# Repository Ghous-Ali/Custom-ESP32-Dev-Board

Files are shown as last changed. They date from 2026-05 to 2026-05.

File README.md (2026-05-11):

# Custom ESP32 Development Board

A from-scratch ESP32-WROOM-32E development board designed in KiCad 9.0.7 on a 4-layer PCB stackup.

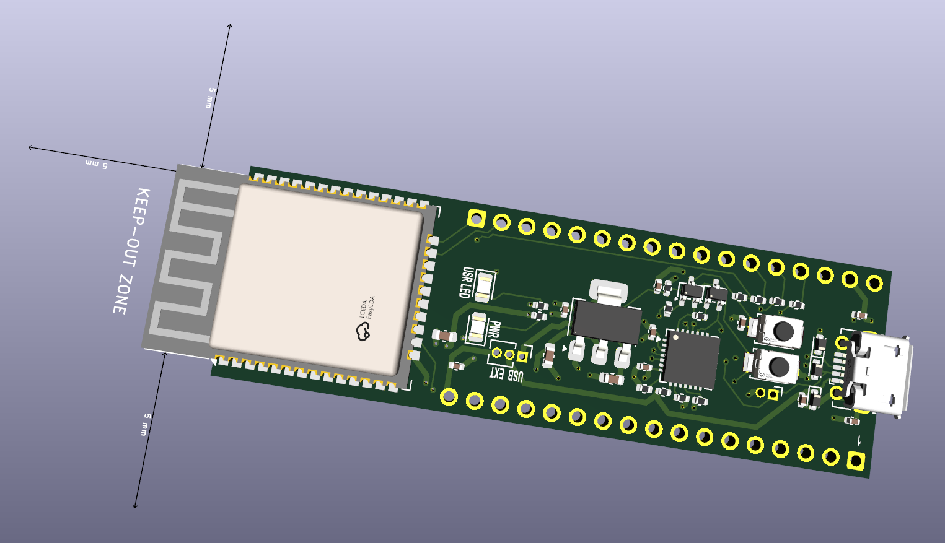
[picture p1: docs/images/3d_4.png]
Front Perspective

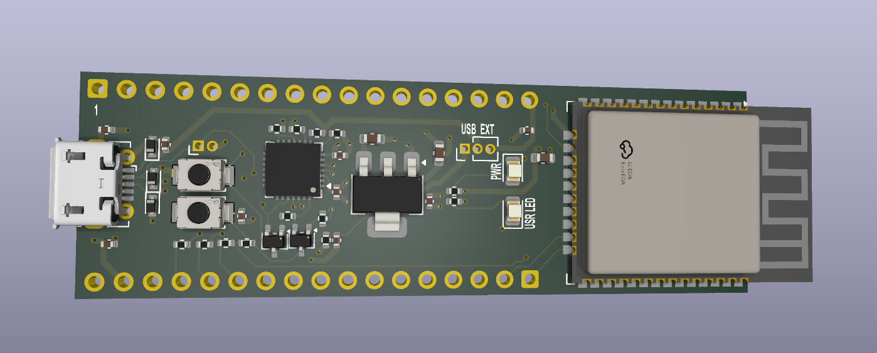
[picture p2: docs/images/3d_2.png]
Top View

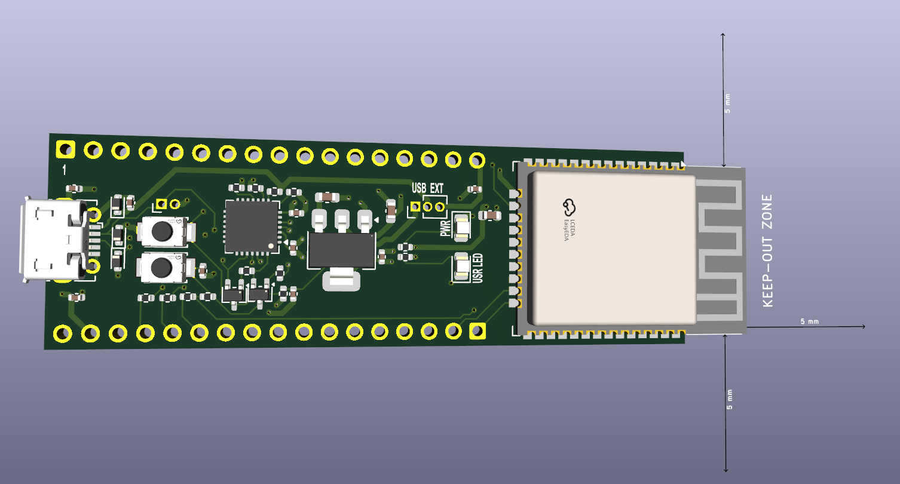
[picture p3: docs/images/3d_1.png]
Front Close-Up

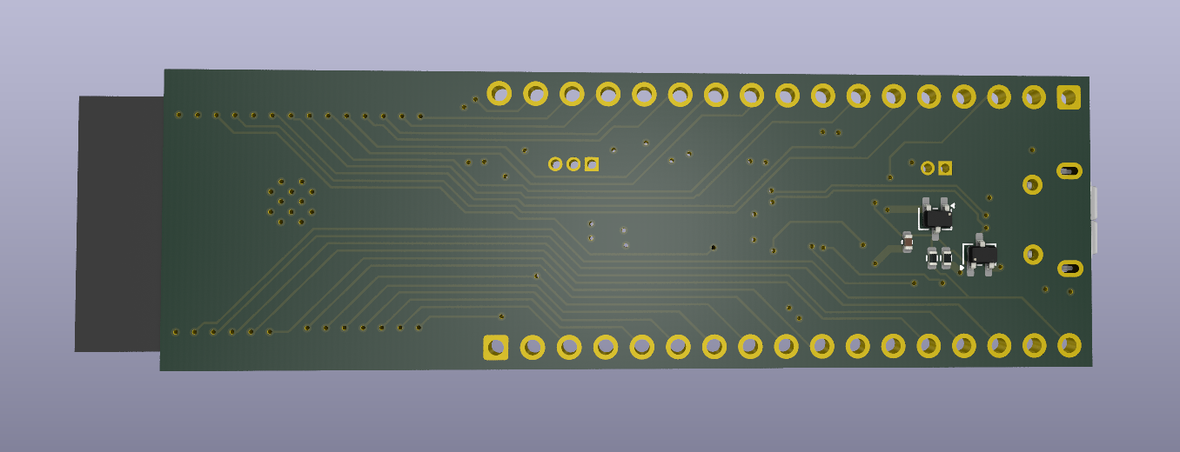
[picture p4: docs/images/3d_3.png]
Back View

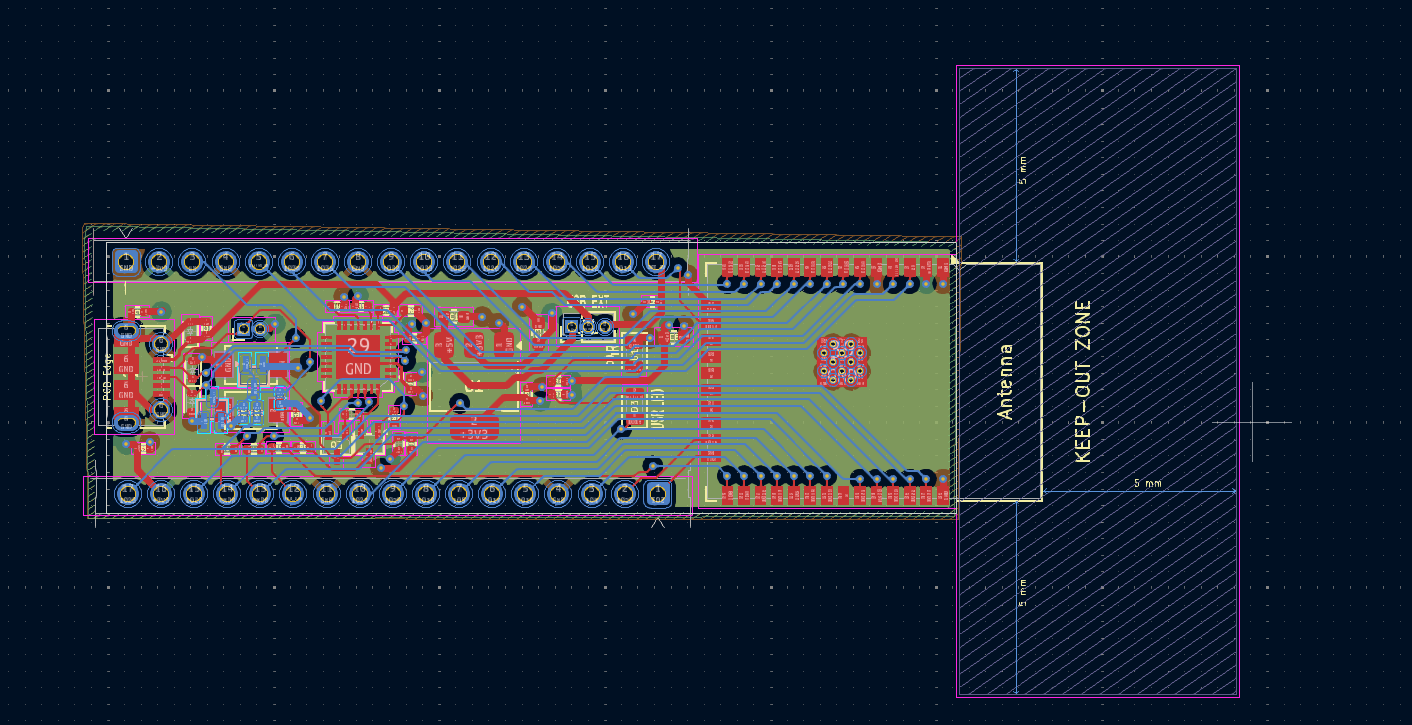
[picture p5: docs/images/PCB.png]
PCB Layout

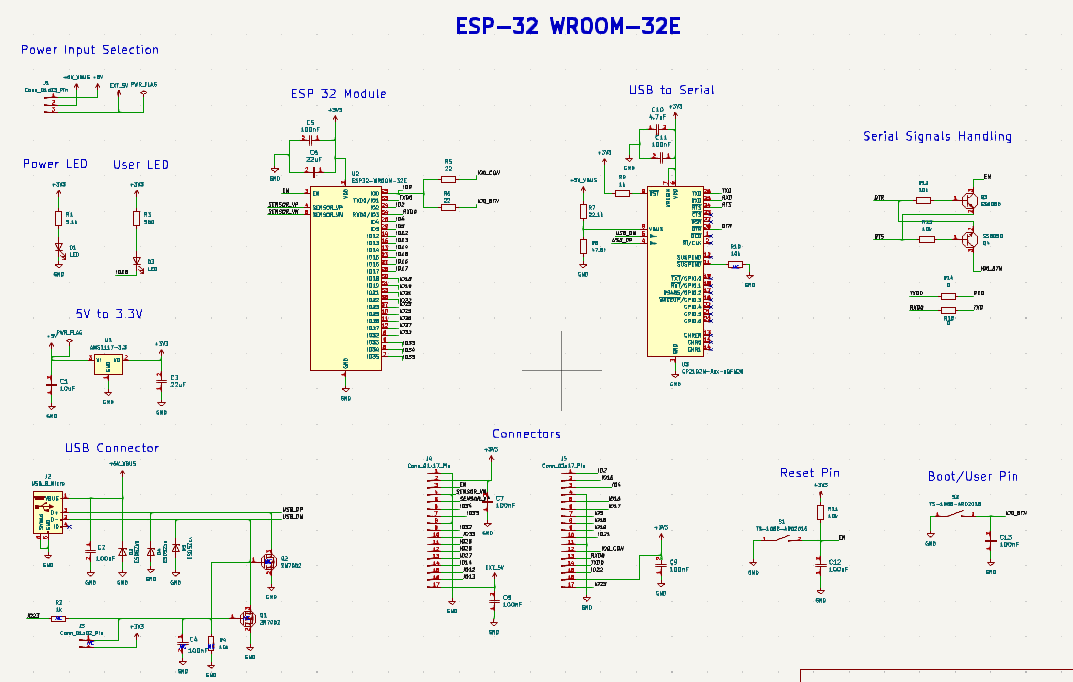
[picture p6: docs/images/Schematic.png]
Schematic


## Features

- **MCU:** ESP32-WROOM-32E (WiFi + Bluetooth, dual-core Xtensa LX6)
- **USB-to-Serial:** CP2102N-A02-GQFN28 with full auto-programming support (DTR/RTS via 2N7002 MOSFETs)
- **Power:** AMS1117-3.3V LDO with 22µF + 100nF input/output filtering; external 5V input option with power path selection
- **ESD Protection:** ESD5Zxx TVS diodes on USB D+/D- lines
- **User Interface:** Boot button, Reset button, Power LED, User LED
- **I/O:** Dual 17-pin headers — breadboard-compatible, exposing all usable GPIOs
- **RF:** Antenna keep-out zone with 5mm clearance on all sides — no copper pour under antenna area
- **PCB:** 4-layer stackup (Signal – GND – Power – Signal), designed for clean return paths and RF performance

## Schematic Overview

| Block | Key Components | Notes |
|---|---|---|
| ESP32 Module | ESP32-WROOM-32E | 38 pins exposed via castellated pads |
| USB-to-Serial | CP2102N, 2N7002 × 2 | Auto-reset circuit for one-click flashing |
| Power Regulation | AMS1117-3.3, SS8050 | 5V USB or external → 3.3V rail |
| ESD Protection | ESD5Zxx × 2 | On USB data lines |
| Decoupling | 100nF × 8, 22µF × 2, 10µF, 4.7µF | Distributed across power pins |

## 4-Layer Stackup Rationale

| Layer | Function |
|---|---|
| F.Cu | Signal routing + component pads |
| In1.Cu | Continuous ground plane |
| In2.Cu | Power distribution (3.3V, 5V) |
| B.Cu | Signal routing + component pads |

A dedicated ground plane on layer 2 ensures low-impedance return paths for high-speed USB signals and minimises EMI. Separating power onto its own inner layer reduces noise coupling to signal traces.

## Design Decisions

- **Auto-reset circuit:** Uses two 2N7002 N-channel MOSFETs driven by DTR and RTS from the CP2102N. This allows tools like `esptool.py` to automatically put the ESP32 into bootloader mode — no manual button pressing needed during upload.
- **Antenna keep-out:** 5mm clearance enforced on all sides of the ESP32 antenna area. No copper, traces, or components in this zone to preserve WiFi/Bluetooth performance.
- **External 5V input:** A 3-pin header (J1) allows powering the board from an external 5V source (e.g., battery pack or bench supply) independently of USB, with SS8050-based switching.
- **Pull-up/pull-down network:** Strapping pins (IO0, IO2, IO5, IO15) are configured via resistor network for default boot-from-flash behaviour.

## Repository Structure

```
Custom_ESP_Dev_Board/
├── hardware/                      # KiCad project files (.kicad_pro, .kicad_sch, .kicad_pcb)
├── production/
│   ├── gerbers/                   # Fabrication files
│   ├── BOM.csv                    # Bill of Materials
│   └── pick-and-place.csv        # Assembly positions
├── docs/
│   ├── images/                    # 3D renders, PCB layout, schematic screenshots
│   └── schematic.pdf             # Exported schematic PDF
├── LICENSE
└── README.md
```

## Tools Used

- **EDA:** KiCad 9.0.7
- **PCB Layers:** 4
- **Design Rules:** JLCPCB 4-layer capabilities (adjust as needed for your fab)

## Getting Started

1. Clone this repo
2. Open the `.kicad_pro` file in KiCad 9.0.7+
3. Generate Gerbers from PCB editor → File → Fabrication Outputs
4. Upload to your preferred PCB fab (JLCPCB, PCBWay, etc.)

## References

- [ESP32-WROOM-32E Datasheet](https://www.espressif.com/sites/default/files/documentation/esp32-wroom-32e_esp32-wroom-32ue_datasheet_en.pdf)
- [ESP32-DevKitC V4 Reference Schematic](https://dl.espressif.com/dl/schematics/esp32_devkitc_v4-sch.pdf)
- [CP2102N Datasheet](https://www.silabs.com/documents/public/data-sheets/cp2102n-datasheet.pdf)

## Licence

This project is open-source hardware. See [LICENSE](LICENSE) for details.

---

Designed by **Ghous Ali** — Electronics & Embedded Systems Engineer  
[LinkedIn](https://www.linkedin.com/in/ghousali13/) · [Email](Ghousali1019@email.com)

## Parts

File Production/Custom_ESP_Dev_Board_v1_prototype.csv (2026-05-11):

Comment | Footprint | Quantity | Designation | LCSC
D5,D4,D2 | D_SOD-523 | 3 | ESD5Zxx | C890620
R13,R11,R12,R10 | R_0402_1005Metric | 4 | 10k | C60490
C8,C11,C5,C7,C2,C12,C9,C13 | C_0402_1005Metric | 8 | 100nF | C60474
U2 | ESP32-WROOM-32D | 1 | ESP32-WROOM-32E | C701342
R7 | R_0402_1005Metric | 1 | 22.1k | C163478
S1,S2 | SW_TS-1088-AR02016 | 2 | TS-1088-AR02016 | C720477
C1 | C_0603_1608Metric | 1 | 10uF | C96446
C6,C3 | C_0603_1608Metric | 2 | 22uF | C59461
J2 | USB_Micro-B_Molex-105017-0001 | 1 | USB_B_Micro | C136000
D3,D1 | LED_0805_2012Metric | 2 | LED | C965815
R14,R15 | R_0402_1005Metric | 2 | 0 | C106231
R3 | R_0402_1005Metric | 1 | 560 | C163460
U3 | QFN-28-1EP_5x5mm_P0.5mm_EP3.35x3.35mm | 1 | CP2102N-Axx-xQFN28 | C964632
U1 | SOT-223-3_TabPin2 | 1 | AMS1117-3.3 | C347222
R9 | R_0402_1005Metric | 1 | 1k | C2906864
R5,R6 | R_0402_1005Metric | 2 | 22 | C114765
Q3,Q4 | SOT-323_SC-70 | 2 | SS8050 | C5189252
R8 | R_0402_1005Metric | 1 | 47.5k | C25896
C10 | C_0402_1005Metric | 1 | 4.7uF | C23733
R1 | R_0402_1005Metric | 1 | 5.1k | C105872

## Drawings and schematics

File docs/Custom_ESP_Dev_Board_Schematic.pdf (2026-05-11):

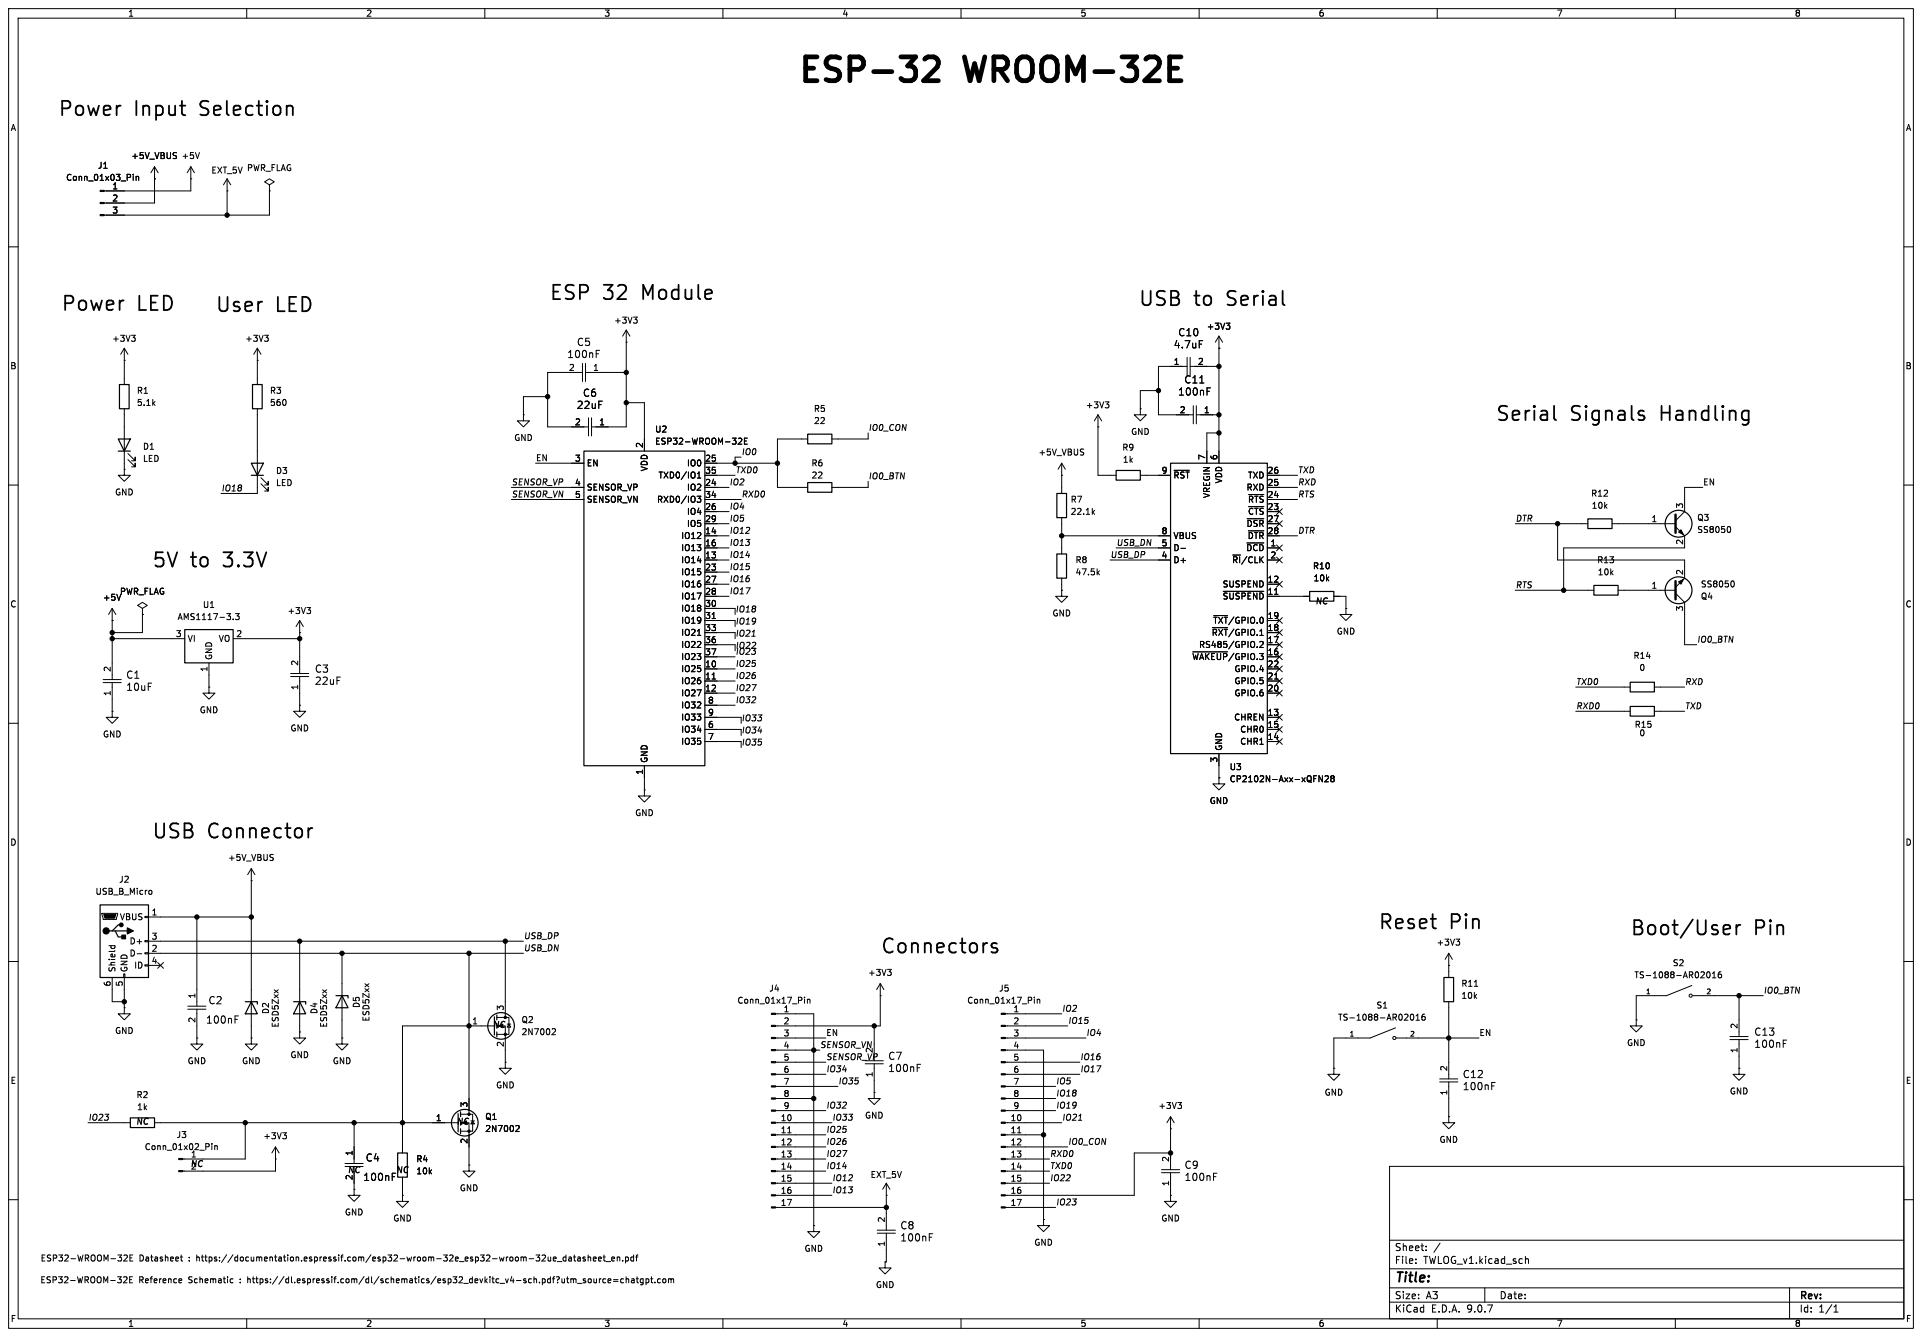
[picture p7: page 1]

3 TXD 26 RXD 25 ~{RTS} 24 ~{CTS} 23 ~{DSR} 27 ~{DTR} 28 ~{DCD}1 ~{RI}/CLK2 SUSPEND 12 ~{SUSPEND}11 ~{TXT}/GPIO.019 ~{RXT}/GPIO.118 RS485/GPIO.2 17 ~{WAKEUP}/GPIO.316 GPIO.4 22 GPIO.5 21 GPIO.6 20 CHREN 13 CHR0 15 CHR1 14 U3 CP2102N-Axx-xQFN28 GND GND

3 TXD 26 RXD 25 ~{RTS} 24 ~{CTS} 23 ~{DSR} 27 ~{DTR} 28 ~{DCD}1 ~{RI}/CLK2 SUSPEND 12 ~{SUSPEND}11 ~{TXT}/GPIO.019 ~{RXT}/GPIO.118 RS485/GPIO.2 17 ~{WAKEUP}/GPIO.316 GPIO.4 22 GPIO.5 21 GPIO.6 20 CHREN 13 CHR0 15 CHR1 14 C4

Id: 1/1 Title: File: TWLOG_v1.kicad_sch Sheet: /

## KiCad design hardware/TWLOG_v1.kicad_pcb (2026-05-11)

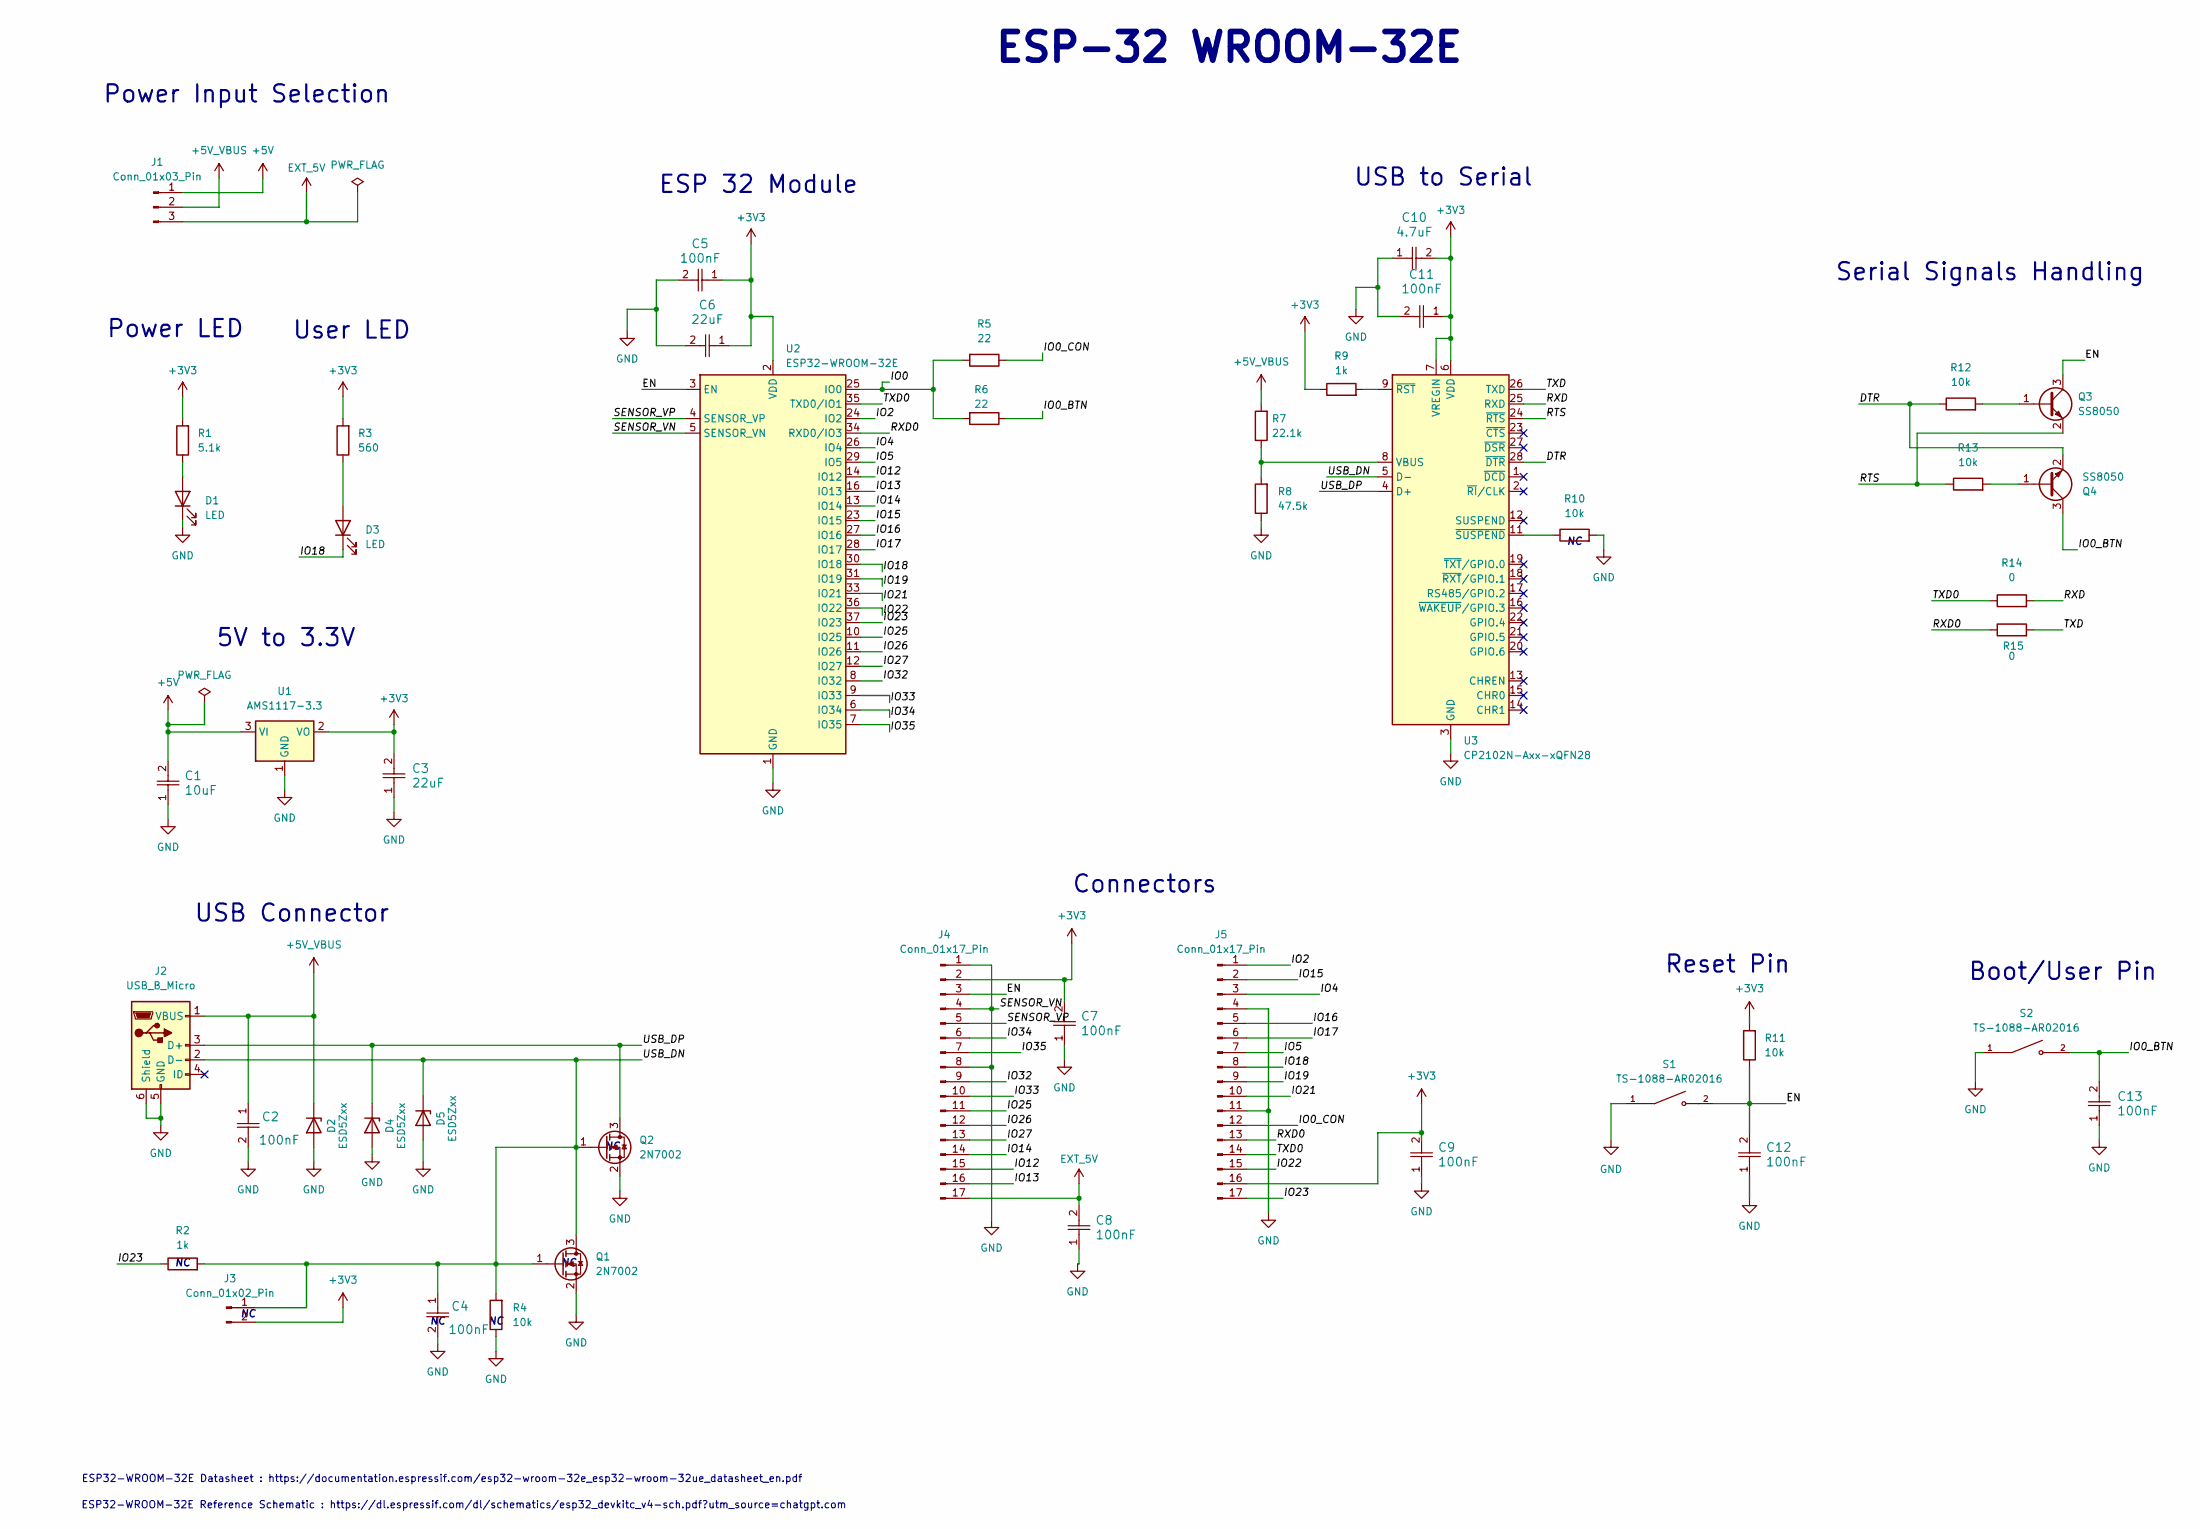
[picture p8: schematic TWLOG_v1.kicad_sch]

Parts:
C1: 10uF; C_0603_1608Metric
C2, C4, C5, C7, C8, C9, C11, C12, C13: 100nF; C_0402_1005Metric
C3, C6: 22uF; C_0603_1608Metric
C10: 4.7uF; C_0402_1005Metric
D1, D3: LED; LED_0805_2012Metric
D2, D4, D5: ESD5Zxx; D_SOD-523
J1: Conn_01x03_Pin; PinHeader_1x03_P1.27mm_Vertical
J2: USB_B_Micro; USB_Micro-B_Molex-105017-0001
J3: Conn_01x02_Pin; PinHeader_1x02_P1.27mm_Horizontal
J4, J5: Conn_01x17_Pin; Molex_SL_171971-0017_1x17_P2.54mm_Vertical
Q1, Q2: 2N7002; SOT-323_SC-70
Q3, Q4: SS8050; SOT-323_SC-70
R1: 5.1k; R_0402_1005Metric
R2, R9: 1k; R_0402_1005Metric
R3: 560; R_0402_1005Metric
R4, R10, R11, R12, R13: 10k; R_0402_1005Metric
R5, R6: 22; R_0402_1005Metric
R7: 22.1k; R_0402_1005Metric
R8: 47.5k; R_0402_1005Metric
R14, R15: 0; R_0402_1005Metric
S1, S2: TS-1088-AR02016; SW_TS-1088-AR02016; PARTREV N/A
U1: AMS1117-3.3; SOT-223-3_TabPin2
U2: ESP32-WROOM-32E; ESP32-WROOM-32D
U3: CP2102N-Axx-xQFN28; QFN-28-1EP_5x5mm_P0.5mm_EP3.35x3.35mm

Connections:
+3V3: C3.2, C5.1, C6.1, C7.2, C9.2, C10.2, C11.1, J3.2, J4.2, J5.16, R1.2, R3.2, R9.1, R11.2, U1.2 (VO), U2.2 (VDD), U3.6 (VDD), U3.7 (VREGIN)
+5V: C1.2, J1.1, U1.3 (VI)
+5V_VBUS: C2.1, D2.1 (K), J1.2, J2.1 (VBUS), R7.2
/DTR: Q4.2 (E), R12.1, U3.28 (~DTR)
/EN: C12.2, J4.3, Q3.3 (C), R11.1, S1.2, U2.3 (EN)
/IO0: R5.2, R6.2, U2.25 (IO0)
/IO0_BTN: C13.2, Q4.3 (C), R6.1, S2.2
/IO0_CON: J5.12, R5.1
/IO2: J5.1, U2.24 (IO2)
/IO4: J5.3, U2.26 (IO4)
/IO5: J5.7, U2.29 (IO5)
/IO12: J4.15, U2.14 (IO12)
/IO13: J4.16, U2.16 (IO13)
/IO14: J4.14, U2.13 (IO14)
/IO15: J5.2, U2.23 (IO15)
/IO16: J5.5, U2.27 (IO16)
/IO17: J5.6, U2.28 (IO17)
/IO18: D3.1 (K), J5.8, U2.30 (IO18)
/IO19: J5.9, U2.31 (IO19)
/IO21: J5.10, U2.33 (IO21)
/IO22: J5.15, U2.36 (IO22)
/IO23: J5.17, R2.1, U2.37 (IO23)
/IO25: J4.11, U2.10 (IO25)
/IO26: J4.12, U2.11 (IO26)
/IO27: J4.13, U2.12 (IO27)
/IO32: J4.9, U2.8 (IO32)
/IO33: J4.10, U2.9 (IO33)
/IO34: J4.6, U2.6 (IO34)
/IO35: J4.7, U2.7 (IO35)
/RTS: Q3.2 (E), R13.1, U3.24 (~RTS)
/RXD: R14.2, U3.25 (RXD)
/RXD0: J5.13, R15.1, U2.34 (RXD0/IO3)
/SENSOR_VP: J4.5, U2.4 (SENSOR_VP)
/TXD: R15.2, U3.26 (TXD)
/TXD0: J5.14, R14.1, U2.35 (TXD0/IO1)
/USB_DN: C4.1, D5.1 (K), J2.2 (D-), J3.1, Q1.1 (G), Q1.3 (D), Q2.1 (G), R2.2, R4.2, U3.5 (D-)
/USB_DP: D4.1 (K), J2.3 (D+), Q2.3 (D), U3.4 (D+)
EXT_5V: C8.2, J1.3, J4.17
GND: C1.1, C2.2, C3.1, C4.2, C5.2, C6.2, C7.1, C8.1, C9.1, C10.1, C11.2, C12.1, C13.1, D1.1 (K), D2.2 (A), D4.2 (A), D5.2 (A), J2.5 (GND), J2.6 (Shield), J4.1, J4.4, J4.8, J5.4, J5.11, Q1.2 (S), Q2.2 (S), R4.1, R8.1, R10.2, S1.1, S2.1, U1.1 (GND), U2.1 (GND), U2.5 (SENSOR_VN), U2.15 (GND), U2.38 (GND), U2.39 (GND), U3.3 (GND), U3.29 (GND)
unnamed: D1.2 (A), R1.1
unnamed: D3.2 (A), R3.1
unnamed: Q3.1 (B), R12.2
unnamed: Q4.1 (B), R13.2
unnamed: R7.1, R8.2, U3.8 (VBUS)
unnamed: R9.2, U3.9 (~RST)
unnamed: R10.1, U3.11 (~SUSPEND)

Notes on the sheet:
Serial Signals Handling
Connectors
ESP32-WROOM-32E Datasheet : https://documentation.espressif.com/esp32-wroom-32e_esp32-wroom-32ue_datasheet_en.pdf
Power LED
Reset Pin
ESP32-WROOM-32E Reference Schematic : https://dl.espressif.com/dl/schematics/esp32_devkitc_v4-sch.pdf?utm_source=chatgpt.com
Power Input Selection
USB Connector
USB to Serial
ESP-32 WROOM-32E
User LED
Boot/User Pin
ESP 32 Module
5V to 3.3V

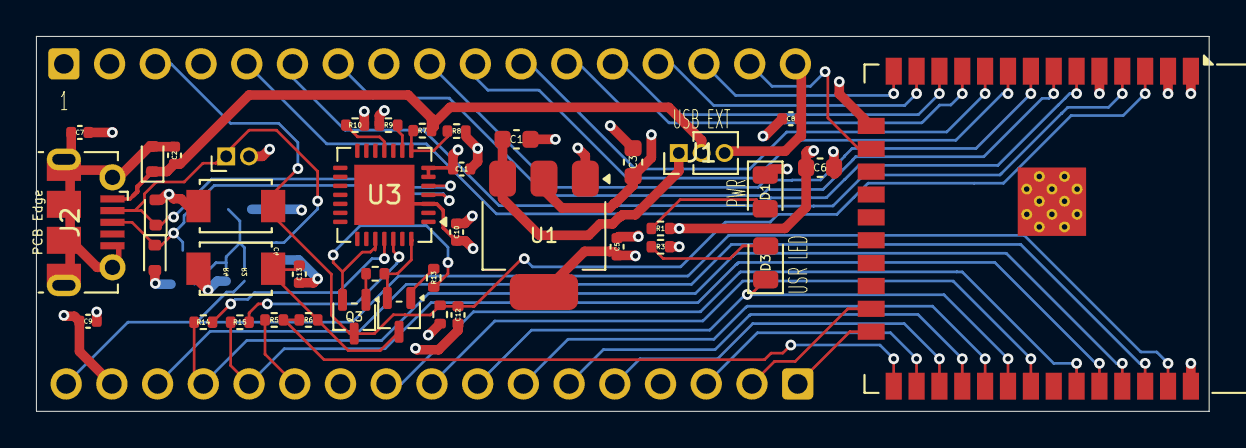
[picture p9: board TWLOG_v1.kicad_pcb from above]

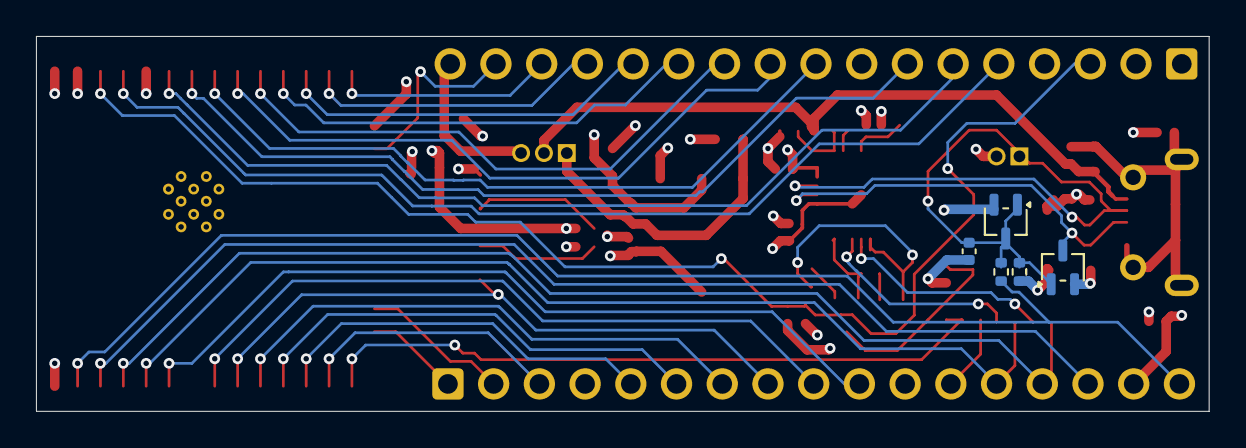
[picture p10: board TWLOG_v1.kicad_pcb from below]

Board: 4 copper layers, 65.2 x 20.8 mm, 47 parts (5 on the bottom side), 46 nets.

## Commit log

2026-05-11 Add KiCad project files
    [TWLOG_v1.kicad_pcb, TWLOG_v1.kicad_sch]
2026-05-11 Add fabrication outputs
    [Custom_ESP_Dev_Board_v1_prototype.csv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]
2026-05-11 Add schematic PDF
